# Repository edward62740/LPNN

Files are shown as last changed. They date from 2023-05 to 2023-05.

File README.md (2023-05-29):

# LPNN
This system runs an always-on neural network for audio classification. Specifically, this project involves the detection of glass breaking and forced entry sounds to provide security at points of ingress. It runs at sub-mW power during inference, allowing for fully battery powered operation and thereby increased deployment flexibility.

## Overview
The device consists of a NDP101 dedicated AI accelerator, SAMD21 microcontroller (on dev board), and an external host MCU for Internet connectivity.

Note: This project is unfinished

## Design
### Hardware
Due to the lack of publicly available information regarding the NDP, direct integration onto a custom board was not feasible.<br>
Hence, its [development board](https://www.syntiant.com/tinyml) was used, and mounted onto a custom board. However, the dev board does not perform well as a low-power system, particularly the 3v3/0v9 LDOs which have high I<sub>Q</sub> of 115μA and 20μA respectively. As such, modifications were made to the board (i.e the regulators are bypassed and 3v3 is supplied externally). The LEDs and IMU were also desoldered.<br>
For some reason, the dev board does not have 3v3 routed to any of the pins (even though there are unused ones), and 0v9 lacks even a test pad.<br>
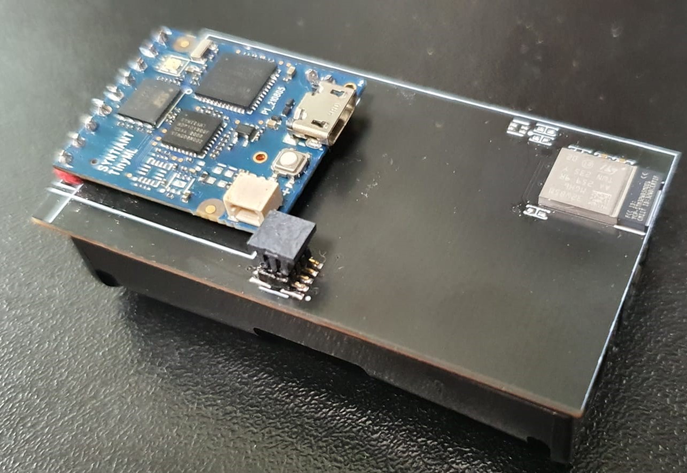
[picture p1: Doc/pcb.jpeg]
PCB


### Software (AI)
The audio signals are transformed into mel spectrograms, most of the feature extraction and DSP is done within the NDP101. Due to hardware limitations, only dense layers can be used, instead of convolutional layers which may be more suited to this case. The NDP101 is configured to interrupt the SAMD21 when a match is found and will communicate the details over SPI.<br>
The SAMD21 then passes the results over LPUART to the STM32WB SiP. Credits to [VOICe Dataset](https://dcase.community/challenge2017/task-rare-sound-event-detection-results) and [this project](https://docs.edgeimpulse.com/experts/prototype-and-concept-projects/vandalism-detection-audio-classification) for the audio datasets used.
The neural network architecture is detailed below:
| Layer | Dimension | Value | Activation |
|---|---|---|---|
| Input | 1600,1 | | |
| Dense | 256,1 | l1=.00001 | relu |
| Dropout | | 0.2 | |
| Dense | 256,1 | l1=.00001 | relu |
| Dropout | | 0.2 | |
| Dense | 256,1 | l1=.00001 | relu |
| Dropout | | 0.2 | |
| Dense | 2,1 | | softmax |
<br>

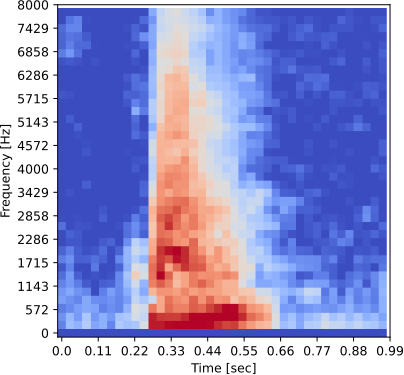
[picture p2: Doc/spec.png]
Spectrogram

<br>*Spectrogram*

## Software (Connectivity)
The device communicates over a IPv6 Thread network and sends positive inference results to the cloud via this [bridge](https://github.com/edward62740/firebase-ingestor-rs).

## Performance

Currently, the model runs (incl. microphone) at 690 μA on 2v5 rail. The breakdown is below.
| Device | Current Draw  (Avg) | Current Draw  (Worst) | Rail |
|---|---|---|---|
| NDP101 | 140μA | |2v5/0v9|
| Microphone |  ? | | 2v5  |
| SAMD21 | <10μA | | |
| 3v3 regulator (ext.) | 500nA | 1000nA | Vbat |
| 0v9 regulator | 20μA | 26μA | 2v5  |
| ~SPI NOR~ | | | |
| Host MCU (ext.) | <10μA | | 2v5  |

It is possible to further improve this figure by decreasing the PDM clk, or by complete redesign of the board to allow for disconnecting the NOR flash etc from supply. 
Alternatively, a different microphone can be used, such as the MMICT5838 which consumes only 120μA at 768kHz. However, the power consumption is sufficient for the intended application, which yields about a year of battery life on 2xAA batteries.

The performance of the model used:
| | **Glass_break** | **Background** | **Uncertain** |
| --- | --- | --- | --- |
| **Glass_break** | 0.89 | 0.09 | 0.02 |
| **Background**  | 0.002 | 0.997 | 0.002 |
| **F1** | 0.93 | 1.00 | |

In practice, the model yields a higher FAR than ideal for a security application, where even very occasional false positives can prove to be disruptive to operations. For instance, the window duration is 968ms, so even a FPR of 1.65e-6 is one disruption a week. Additional window delay/suppression algorithms may need to be considered. However, this project is a sufficient proof-of-concept for intended further development. A future improvement will be to use the NDP120 (newer IC), which also provides 2d conv layers.

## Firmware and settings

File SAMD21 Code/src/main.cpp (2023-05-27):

#include "main.h"
#include <NDP.h>
#include <NDP_utils.h>
#include <Arduino.h>
#include "TinyML_init.h"
#include "NDP_init.h"
#include "NDP_loadModel.h"
#include "SAMD21_init.h"
#include "SAMD21_lowpower.h"
#include "LowPower.h"
#include "hostcmd.h"

Uart ext(&sercom3, 7, 6, SERCOM_RX_PAD_3, UART_TX_PAD_2); // UART for communication with host mcu

static volatile classifier_match_t s_match;
static void ndp_isr(void) { s_match = (classifier_match_t)NDP.poll(); }



void SERCOM3_Handler()
{
    ext.IrqHandler();
}

void service_ndp() {

  hostcmd_send_classifier_match(s_match);
  
  switch (s_match) {

  case GLASS_BREAK:
    digitalWrite(LED_BLUE, HIGH);
    delay(250);
    digitalWrite(LED_BLUE, LOW);
    break;

  case Z_OPENSET:
    digitalWrite(LED_GREEN, HIGH);
    delay(250);
    digitalWrite(LED_GREEN, LOW);
    break;

  default:
    break;
  }
}


void setup(void) {
  // Initialize the SAMD21 host processor
  SAMD21_init(0);

  ext.begin(115200);
  //pinPeripheral(6, PIO_SERCOM_ALT);                       //The 7th pin of TinyML board is setup for Serial2 debug. Please not 6 is Arduino pin mapping
  //pinPeripheral(7, PIO_SERCOM_ALT);                     // Since there is nothing expected from serial2 this pin is commented out

  NDP_init("ei_model.bin", 0);

  attachInterrupt(NDP_INT, ndp_isr, HIGH);
  
  // Prevent the internal flash memory from powering down in sleep mode
  NVMCTRL->CTRLB.bit.SLEEPPRM = NVMCTRL_CTRLB_SLEEPPRM_DISABLED_Val;
  // Select STANDBY for sleep mode
  SCB->SCR |= SCB_SCR_SLEEPDEEP_Msk;
   usb_serial_disable(); // See note above about USB communications
}

void loop() {

  // Put various peripheral modules into low power mode before entering standby.
  digitalWrite(LED_GREEN, LOW);
  digitalWrite(LED_BLUE, LOW);
  digitalWrite(LED_RED, LOW);
  adc_disable();        // See SAMD21_lowpower.h
 
  systick_disable();
  // Complete any memory operations and enter standby mode until an interrupt
  // is recieved from the NDP101
  __DSB();
  __WFI();
  
  // Arrive here after waking and having called ndp_isr().  Re-enable various
  // peripheral modules before servicing the NDP classifier data.
  systick_enable();
 // usb_serial_enable();
  adc_enable();
  // process the classifier data from the NDP
  service_ndp();
}

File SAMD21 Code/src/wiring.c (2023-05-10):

/*
  Copyright (c) 2015 Arduino LLC.  All right reserved.

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
  You should have received a copy of the GNU Lesser General Public
  License along with this library; if not, write to the Free Software
  Foundation, Inc., 51 Franklin St, Fifth Floor, Boston, MA  02110-1301  USA
*/

#include "Arduino.h"

#ifdef __cplusplus
extern "C" {
#endif

/*
 * System Core Clock is at 1MHz (8MHz/8) at Reset.
 * It is switched to 48MHz in the Reset Handler (startup.c)
 */
uint32_t SystemCoreClock=1000000ul ;

/*
void calibrateADC()
{
  volatile uint32_t valeur = 0;

  for(int i = 0; i < 5; ++i)
  {
    ADC->SWTRIG.bit.START = 1;
    while( ADC->INTFLAG.bit.RESRDY == 0 || ADC->STATUS.bit.SYNCBUSY == 1 )
    {
      // Waiting for a complete conversion and complete synchronization
    }

    valeur += ADC->RESULT.bit.RESULT;
  }

  valeur = valeur/5;
}*/

/*
 * Arduino Zero board initialization
 *
 * Good to know:
 *   - At reset, ResetHandler did the system clock configuration. Core is running at 48MHz.
 *   - Watchdog is disabled by default, unless someone plays with NVM User page
 *   - During reset, all PORT lines are configured as inputs with input buffers, output buffers and pull disabled.
 */
void init( void )
{
  // Set Systick to 1ms interval, common to all Cortex-M variants
  if ( SysTick_Config( SystemCoreClock / 1000 ) )
  {
    // Capture error
    while ( 1 ) ;
  }
  NVIC_SetPriority (SysTick_IRQn,  (1 << __NVIC_PRIO_BITS) - 2);  /* set Priority for Systick Interrupt (2nd lowest) */

  // Clock PORT for Digital I/O
//  PM->APBBMASK.reg |= PM_APBBMASK_PORT ;
//
//  // Clock EIC for I/O interrupts
//  PM->APBAMASK.reg |= PM_APBAMASK_EIC ;

  // Clock SERCOM for Serial
  PM->APBCMASK.reg |= PM_APBCMASK_SERCOM0 | PM_APBCMASK_SERCOM1 | PM_APBCMASK_SERCOM2 | PM_APBCMASK_SERCOM3 | PM_APBCMASK_SERCOM4 | PM_APBCMASK_SERCOM5 ;

  // Clock TC/TCC for Pulse and Analog
  PM->APBCMASK.reg |= PM_APBCMASK_TCC0 | PM_APBCMASK_TCC1 | PM_APBCMASK_TCC2 | PM_APBCMASK_TC3 | PM_APBCMASK_TC4 | PM_APBCMASK_TC5 ;

  // Clock ADC/DAC for Analog
  PM->APBCMASK.reg |= PM_APBCMASK_ADC | PM_APBCMASK_DAC ;

// Defining VERY_LOW_POWER breaks Arduino APIs since all pins are considered INPUT at startup
// However, it really lowers the power consumption by a factor of 20 in low power mode (0.03mA vs 0.6mA)
//#define VERY_LOW_POWER // [rdp]

  // Setup all pins (digital and analog) in INPUT mode (default is nothing)
  for (uint32_t ul = 0 ; ul < NUM_DIGITAL_PINS ; ul++ )
  {
    pinMode( ul, INPUT_PULLUP ) ;
  }


  // Initialize Analog Controller
  // Setting clock
  while(GCLK->STATUS.reg & GCLK_STATUS_SYNCBUSY);

  GCLK->CLKCTRL.reg = GCLK_CLKCTRL_ID( GCM_ADC ) | // Generic Clock ADC
                      GCLK_CLKCTRL_GEN_GCLK0     | // Generic Clock Generator 0 is source
                      GCLK_CLKCTRL_CLKEN ;

  while( ADC->STATUS.bit.SYNCBUSY == 1 );          // Wait for synchronization of registers between the clock domains

  ADC->CTRLB.reg = ADC_CTRLB_PRESCALER_DIV512 |    // Divide Clock by 512.
                   ADC_CTRLB_RESSEL_10BIT;         // 10 bits resolution as default

  ADC->SAMPCTRL.reg = 0x3f;                        // Set max Sampling Time Length

  while( ADC->STATUS.bit.SYNCBUSY == 1 );          // Wait for synchronization of registers between the clock domains

  ADC->INPUTCTRL.reg = ADC_INPUTCTRL_MUXNEG_GND;   // No Negative input (Internal Ground)

  // Averaging (see datasheet table in AVGCTRL register description)
  ADC->AVGCTRL.reg = ADC_AVGCTRL_SAMPLENUM_1 |    // 1 sample only (no oversampling nor averaging)
                     ADC_AVGCTRL_ADJRES(0x0ul);   // Adjusting result by 0

  analogReference( AR_DEFAULT ) ; // Analog Reference is AREF pin (3.3v)

  // Initialize DAC
  // Setting clock
  while ( GCLK->STATUS.reg & GCLK_STATUS_SYNCBUSY );
  GCLK->CLKCTRL.reg = GCLK_CLKCTRL_ID( GCM_DAC ) | // Generic Clock ADC
                      GCLK_CLKCTRL_GEN_GCLK0     | // Generic Clock Generator 0 is source
                      GCLK_CLKCTRL_CLKEN ;

  while ( DAC->STATUS.bit.SYNCBUSY == 1 ); // Wait for synchronization of registers between the clock domains
  DAC->CTRLB.reg = DAC_CTRLB_REFSEL_AVCC | // Using the 3.3V reference
                   DAC_CTRLB_EOEN ;        // External Output Enable (Vout)
}

#ifdef __cplusplus
}
#endif

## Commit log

2023-05-11 Updated LP code test
    [LPNN.PrjPcb, PCB.PcbDoc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]
2023-05-11 Updated PCB (final)
    [PCB_Copper_Signal_Bot.gbr, PCB_Copper_Signal_Top.gbr, PCB_Legend_Bot.gbr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]
2023-05-13 Updated LP config
    [LPNN.PrjPcb, PCB.PcbDoc, main.SchDoc]
2023-05-27 Updated comms and doc
    [PCB.PcbDoc, main.SchDoc]
